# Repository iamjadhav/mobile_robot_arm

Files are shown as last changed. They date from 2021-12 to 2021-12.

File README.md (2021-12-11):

## Mobile Robot Arm

---

## Contributors

1) [Rajan Pande](https://github.com/rpande1996)
Graduate Student of M.Eng Robotics at University of Maryland. 
2) [Aditya Jadhav](https://github.com/iamjadhav)
Graduate Student of M.Eng Robotics at University of Maryland.

## Overview

In today’s rapidly advancing technological world, the ease of access to products and the speed as well as quality with which they are delivered are extremely important. Most of
the companies in the modern world are aware of the advantages these factors bring to their revenue. But to achieve these couple of objectives, they need to act smartly and reduce costs
wherever they can. Reducing production, packaging and shipment costs goes way beyond helping achieve those objectives. And of course, technology plays a significant part of that
advancement. Bringing down labor costs in terms of salary and benefits helps in reducing the aforementioned costs of the companies. Having smart, efficient and low-maintenance
workforce can lead to even greater benefits in saving revenue. Industrial Robots is the proven answer to this question of satisfying customer needs with speed and efficiency to stay or even
get ahead of the competition. Our aim is to build an Mobile Industrial Robot Arm that is designed to help with the loading and unloading of product shipment. While building this Robot Arm,
we intend to make use of smart sensing to have the robot become as automated as possible. The development of the packaging environment is also one of our main subtasks to implement the
entire system. We will be aiming to achieve maximum speed and efficiency in our process of loading and unloading by refining our system elements.

The results are avilable in the Demo section.
The technologies(libraries, tools, systems) used in order to build this project are listed in the next section.

## Technology Used

* Ubuntu 18.04 LTS
* ROS Melodic
* Python Programming Language
* CMake Build System
* SolidWorks Software
* IKpy Library
* Rviz
* Gazebo
* Numpy Library
* Sympy Library

## License 

```
MIT License

Copyright (c) 2021 Rajan Pande, Aditya Jadhav

Permission is hereby granted, free of charge, to any person obtaining a copy
of this software and associated documentation files (the "Software"), to deal
in the Software without restriction, including without limitation the rights
to use, copy, modify, merge, publish, distribute, sublicense, and/or sell
copies of the Software, and to permit persons to whom the Software is
furnished to do so, subject to the following conditions:

The above copyright notice and this permission notice shall be included in all
copies or substantial portions of the Software.

THE SOFTWARE IS PROVIDED "AS IS", WITHOUT WARRANTY OF ANY KIND, EXPRESS OR
IMPLIED, INCLUDING BUT NOT LIMITED TO THE WARRANTIES OF MERCHANTABILITY,
FITNESS FOR A PARTICULAR PURPOSE AND NONINFRINGEMENT. IN NO EVENT SHALL THE
AUTHORS OR COPYRIGHT HOLDERS BE LIABLE FOR ANY CLAIM, DAMAGES OR OTHER
LIABILITY, WHETHER IN AN ACTION OF CONTRACT, TORT OR OTHERWISE, ARISING FROM,
OUT OF OR IN CONNECTION WITH THE SOFTWARE OR THE USE OR OTHER DEALINGS IN THE 
SOFTWARE.
```

## Demos

Gazebo Demo:

- [Final Pick and Place](https://www.youtube.com/watch?v=QyFkN3RfSUs)

Rviz Demo:

- [Rviz](https://www.youtube.com/watch?v=fZ4QtwVQR7c)

## How to Build and run scripts

- Setup: Navigate to the launch folder and open final_world.world file
and replace "/<your-workspace-location>/" with your workspace location. Otherwise the 
world will not load properly.

- Demo - cd into the catkin_ws/src and type in, 

```
git clone --recursive https://github.com/iamjadhav/mobile_robot_arm
cd ..
catkin_make
source devel/setup.bash
roslaunch robot_arm arm_launch.launch
```

- To run tele-op for mobile base or arm links, open another terminal,
cd into the src folder of the package and type,

```
python teleop_template.py/arm_movements.py
```

- FK and IK validation: cd into kinematics_validation folder of the package and run,

```
python forward_kinematics.py/inverse_kinematics.py
```

- Jacobian and T-matrices: cd into kinematics_validation folder of the package and run,

```
python jacobian_calculator.py
``` 

## Set of Assumptions 

- The environment of the robot (world) obeys gravity, and the surface is continuous
  and flat.
- The objects are placed on the edge of the platforms so as to be within the workspace
  of the Robot Arm when it moves closer to them.
- The obstacles are detected by the laser and a soft warning is displayed. It is
  assumed that the operator is on the lookout for such warnings when the robot arm
  is visibly close to any obstacle.
- The platform heights are adjusted according to the workspace of the robot arm.
- The end-effector of the robot arm is designed considering the shape of the object.
  They make grasping of the object drastically convenient.

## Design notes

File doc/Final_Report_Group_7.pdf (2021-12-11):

## ENPM662 Introduction to Robot Modeling Final Project Proposal

## Mobile Industrial Robot Arm

Authors: Rajan Pande (117306002) & Aditya Jadhav (117389616)

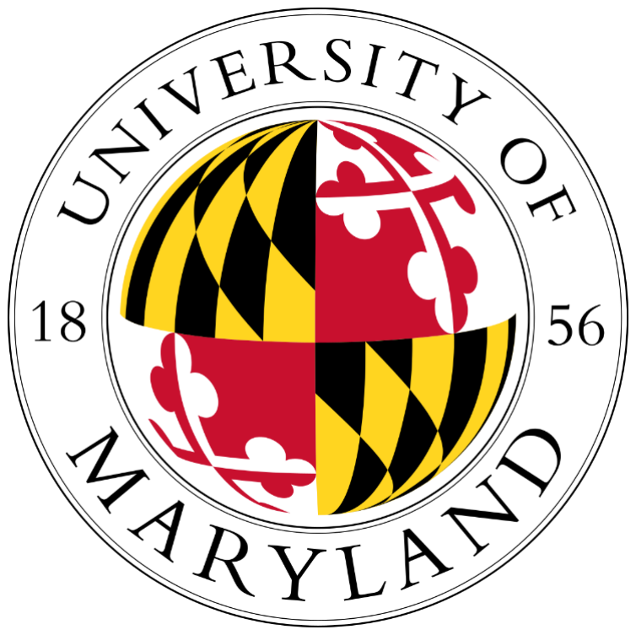
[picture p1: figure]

## Table of Contents

## Introduction

This document provides an in-depth report for our ENPM662 Final Project Mobile Robot Industrial Arm. The document provides an in-depth proposal for ENPM662 Project 2. The document contains different sections each with information about certain aspects of the project. The project was concerned with developing a mobile robot arm of industrial standards from scratch. The ‘Introduction’ section describes the structure of the report. ‘Application’ section describes the applications that this robot can be deployed for a useful function. The sections ‘Robot Type’ and ‘Dimensions’ detail the in-depth information of the type, structure of the robot, its specifications and physical dimensions, material, and actuators used, and the system specifications. The ‘CAD models’ section describes and demonstrates the different stages of the development of the mobile robot arm. The next section ‘DH Parameters’ shows the Denavit-Hartenberg parameters of the mobile robot arm which are calculated using the Spong’s convention. Next four sections are ‘Forward Kinematics & Inverse Kinematics’, ‘Forward Kinematics Validation & Inverse Kinematics Validation’ respectively and are the sections about our study of the Forward and Inverse Kinematics of the mobile robot arm and the validation of FK and IK.
Section ‘Workspace Study’ describes the workspace of the mobile robot arm containing the maximum reach of the arm with its available joint rotations. ‘Assumptions’ section states the assumptions of the project for producing the optimal output out of the developed system. The next section ‘Control Method’ is about the control mechanism used for the mobile robot arm which is the Proportional-Integral-Derivative controller. It also outlines the types of ROS controllers that exist and the ones that are used for the arm. The ‘Gazebo Visualization’ is mainly about the Gazebo setup of the project containing details about the custom world and its components as well as the entire setup with the arm. ‘RViz Visualization’ highlights the laser outputs which are obtained from RViz for the LaserScan topic. Sections ‘Problems’ and ‘Lessons Learned’ represent the problems we faced during several stages of the development process and the solutions/learnings we deployed. ‘Conclusion’ section summarizes the project outcomes and concludes the project. ‘Future Works’ outlines the ambitious goals that can be achieved building on this project. Finally, the ‘References’ section enlists the references we used to acquire knowledge about different aspects of Robot Modeling and our project.

## Application

The primary motivation for us to work on this project was the Stretch (https://spectrum.ieee.org/stretch-is-boston-dynamics-take-on-a-practical-mobile-manipulator-for-warehouses) Robot developed by Boston Dynamics, which is deployed for mobile, automated case handling for more efficient warehouse operations. Stretch is a versatile mobile robot for case handling, designed for easy deployment in existing warehouses. It unloads trucks and builds pallets faster, eliminating the need for new fixed infrastructure. It can be used to automate case handling anywhere in the warehouse with advanced mobility, reducing the need for fixed infrastructure. The Stretch Robot boasts advanced perception which delivers fast and precise case detection. It has a 7 degrees-of-freedom manipulator arm which allows for long reach and large workspace. It also contains embedded sensing and active control which handles variety of package types while operating at high speeds. The lost lucrative feature of the Stretch Robot for us was the mobile base. We draw inspiration from the mobile base which maneuvers in any direction and navigates obstacles and ramps.
As we were working through the different phases of our development process, we had to change the design of the overall robot as well as the robot arm. We faced problems with center of gravity of the system, the limiting torque of each joint (these will be detailed in the ‘Problems’ section). Consequently, we had to adapt our robots design to overcome these problems. We decided that we will look for inspiration in a robot which is a crucial part of human history, The Mars Rover Curiosity. (https://mars.nasa.gov/msl/spacecraft/rover/arm/) Although, possessing abilities far beyond the ones we desired, it was perfect to look up to for us and proceed with our project.
The mobile robot arm applications such as the ones described above are extremely ambitious real-life applications. Our mobile robot arm, however, is not yet capable of such complex applications, but can definitely achieve the core objectives of Pick ‘n’Place operations in a known and controlled environment.

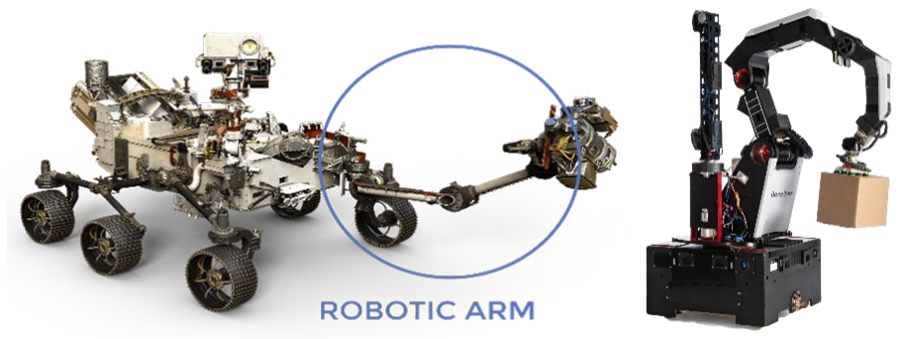
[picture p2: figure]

Figure 1: Curiosity (left) and Stretch (right)

## Robot Type

Under the umbrella of a multitude of currently recognized robot types (https://robots.ieee.org/learn/types-of-robots/) in the world, our mobile robot arm falls under the Industrial Robot Type. An Industrial Robot is a robot system used for manufacturing and its related processes. Industrial Robots are automated, programmable, and capable of movement on three or more axes. Typical applications of robots include welding, painting, assembly, disassembly, pick and place, packaging and labeling, palletizing, product inspection and testing; all accomplished with high endurance, speed, and precision. They can assist in material handling.
The robot arm developed in this project belongs to the Articulated Robots type in Industrial Robots. Articulated Robots are the most common Industrial Robots. They look like a human arm, which is why they are also called robotic arm or manipulator arm. Their articulations with several degrees-of-freedom allow the articulated arms a wide range of movements.

## Dimensions

We have developed a 6 DOF manipulator on a 2 DOF mobile base:

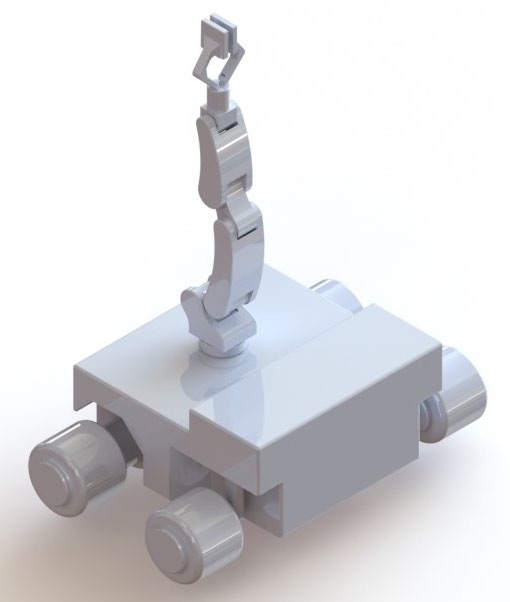
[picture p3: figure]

Property | Dimension
Total Length | 2.00 m
Total Width | 3.22 m
Total Height | 3.91 m
Vertical Reach | 3.98 m
Horizontal Reach | 2.16 m
Wheelbase | 1.25 m
Trackwidth | 2.62 m
Wheel Diameter | 0.62m
Wheel Thickness | 0.50 m
Rotating Arm Length | 0.42 m
Extending Arm Length | 0.90 m
Picking Arm Length | 0.88 m
Jaw Arm Length | 0.30 m
Jaw Length | 0.54 m

## CAD Models

### 1. Robot Arm 1.0:

The initial design had a simple design which would satisfy our basic fallback requirements. However, the drawback of this design was that it had a smaller workspace.

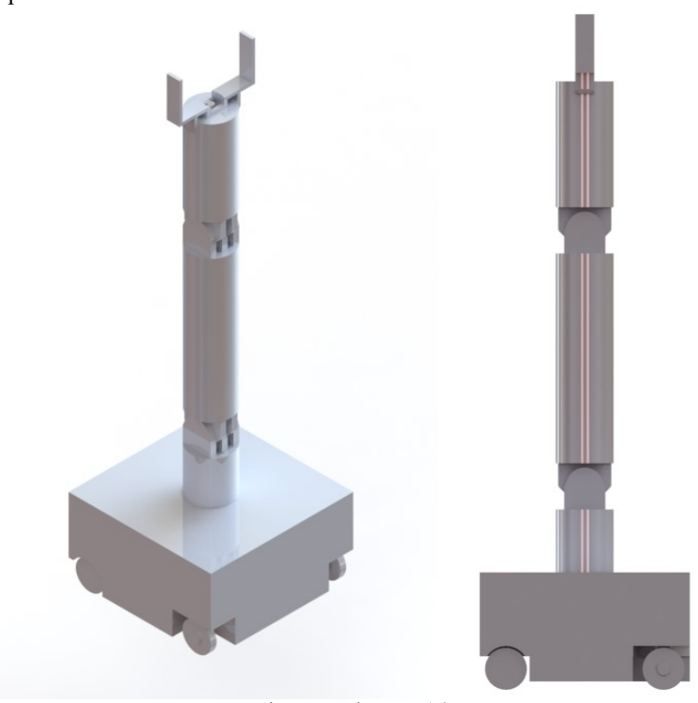
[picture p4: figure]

Figure 3: Robot Arm 1.0

### 2. Robot Arm 2.0:

To increase the workspace, we required to make a few changes to arm design. The major drawback of this design was inability to operate the jaws in ROS.

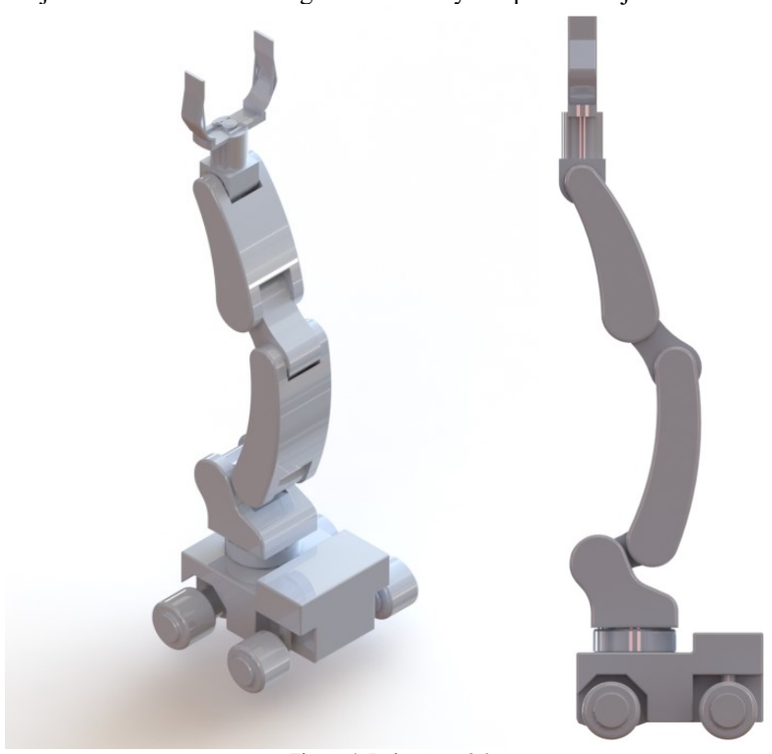
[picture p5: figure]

Figure 4: Robot Arm 2.0

### 3. Robot Arm 3.0:

We thought, maybe the issue with the earlier design was the complicated jaw mechanism. So, we converted it to a simple prismatic joint. However, we weren’t still able to actuate the jaws.

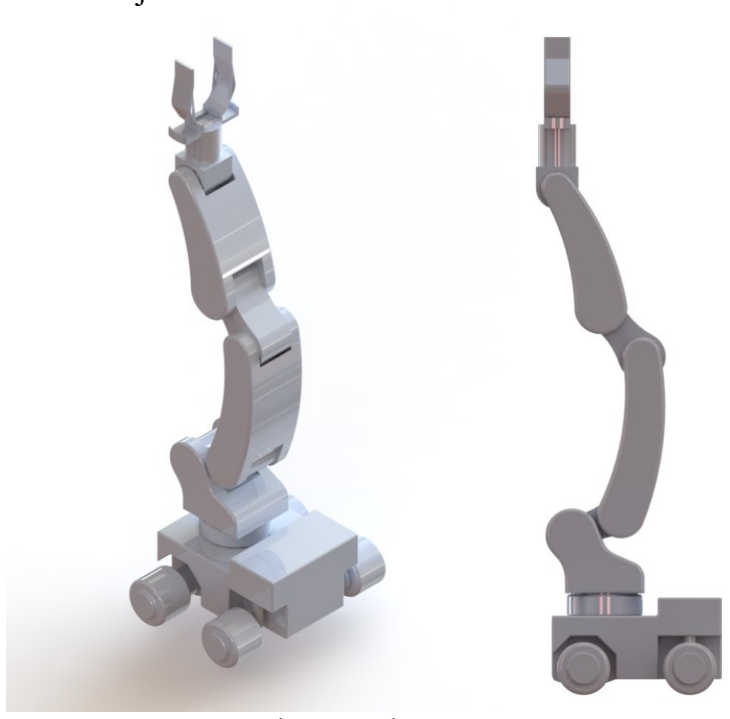
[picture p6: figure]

Figure 5: Robot Arm 3.0

### 4. Robot Arm 4.0:

We finally came up with a solution of designing a simple revolute mechanism for the jaws. Additionally, to increase the stability of the robot, we designed a wider mobile base for the manipulator.

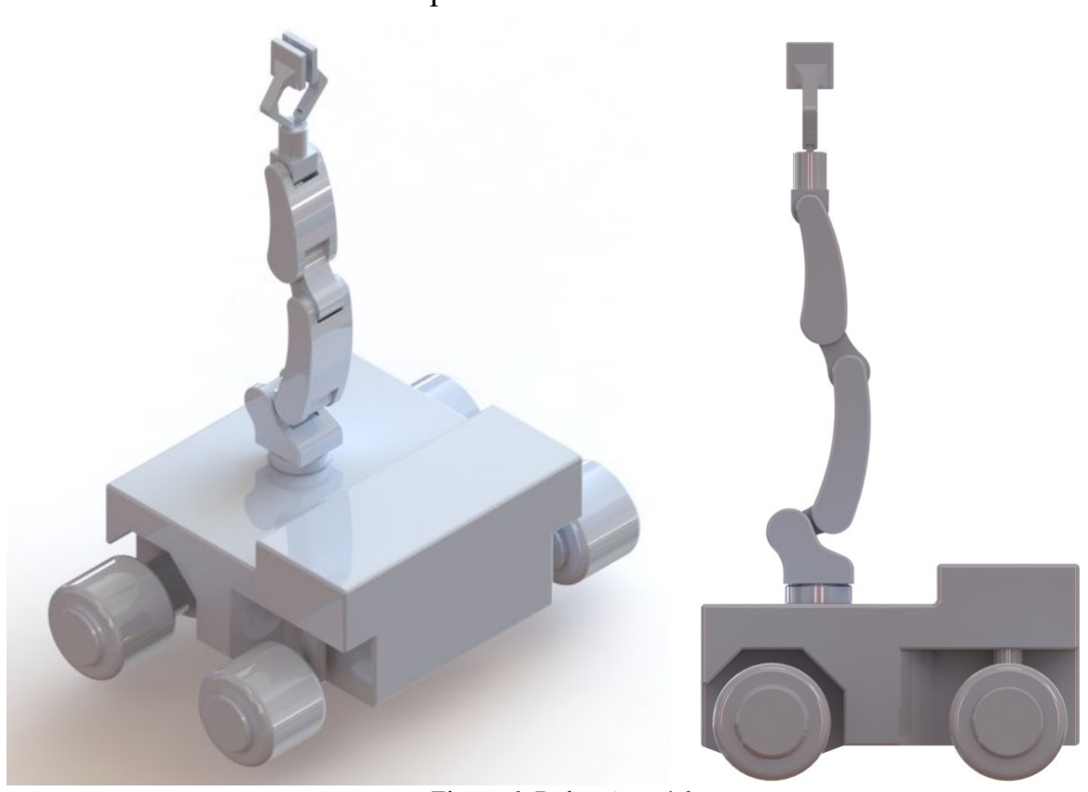
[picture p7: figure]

Figure 6: Robot Arm 4.0

## DH Parameters

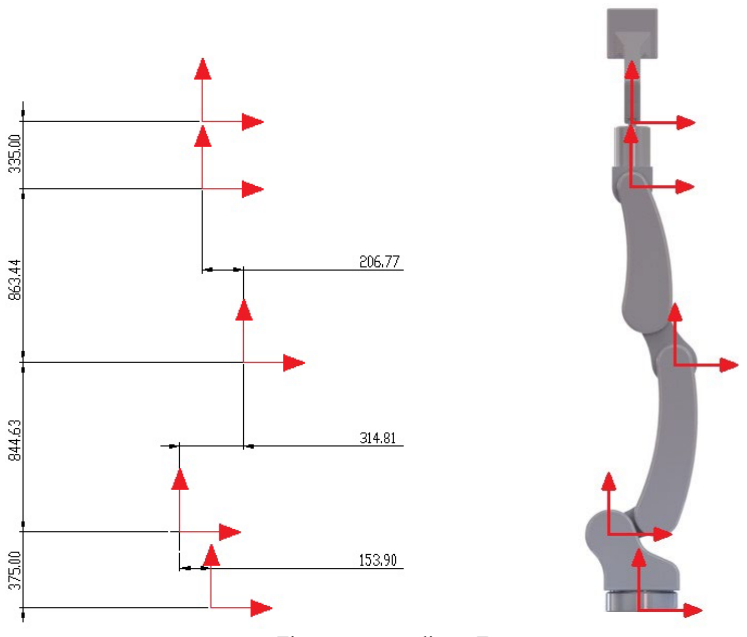
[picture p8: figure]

Figure 7: Co-ordinate Frame

Link | ai | di | αi | di
1 | 153.90 | 375 | π/2 | th1*
2 | 314.81 | 844.63 | 0 | th2*
3 | 206.77 | 863.44 | 0 | th3*
4 | 0 | 335 | 0 | th4*

## Forward Kinematics and Inverse Kinematics

Jacobian and Transformation Matrix Calculator:

1. import numpy as np
2. import sympy as sy
3. from sympy import nsimplify 4.
5. def s(x):
6. return sy.sin(x)
7.
8. def c(x):
9. return sy.cos(x)
10.
11. th, al, a, d, th1, th2, th3, th4, Z1, Z2, Z3, Z4, d1, d2, d3, d4, t = sy.symbols(
12. 'th, al, a, d, th1, th2, th3, th4, Z1, Z2, Z3, Z4, d1, d2, d3, d4, t')
13.
14. A = sy.Matrix([[c(th), -s(th) * c(al), s(th) * s(al), a * c(th)],
15. [s(th), c(th) * c(al), -c(th) * s(al), a * s(th)],
16. [0, s(al), c(al), d],
17. [0, 0, 0, 1]])
18.
19. th_list = [th1, th2, th3, th4]
20. al_list = [pi / 2, 0, 0, 0]
21. d_list = [375, 844.63, 863.44, 335]
22. a_list = [153.9, 314.81, 206.77, 0]
23. init_th = [pi/3, 0, -pi/4, pi]
24.
25. def calculate_A_matrix(ali, ai, thi, di):
26. | global A, e | A_transform = nsimplify(A.subs({al: ali, a: ai, th: thi, d: di}),
27. tolerance=1e-3, rational=True)
28. return A_transform
29.
30. def calculate_T_matrix():
31. A1 = calculate_A_matrix(al_list[0], a_list[0], th_list[0], d_list[0])
32. A2 = calculate_A_matrix(al_list[1], a_list[1], th_list[1], d_list[1])
33. A3 = calculate_A_matrix(al_list[2], a_list[2], th_list[2], d_list[2])
34. A4 = calculate_A_matrix(al_list[3], a_list[3], th_list[3], d_list[3]) 35.
36. T1 = A1
37. T2 = (T1 * A2)
38. T3 = (T2 * A3)
39. T4 = (T3 * A4)
40. return T1, T2, T3, T4
41.
42. T1, T2, T3, T4 = calculate_T_matrix() 43.
44. def ZMatrix_calculator(T1, T2, T3, T4):
45. Z1 = T1[:3, 2]
46. Z2 = T2[:3, 2]
47. Z3 = T3[:3, 2]
48. Z4 = T4[:3, 2]
49. ZMatrix = [Z1, Z2, Z3, Z4]
50. return ZMatrix
51.
52. def Jcalculator(joint_angle):
53. global T4
54. th = [th1, th2, th3, th4]
55. Th_values = [joint_angle[0], joint_angle[1], joint_angle[2], joint_angle[3]] 56.
57. j = T4[:3, 3]
58. ZMatrices = ZMatrix_calculator(T1, T2, T3, T4)
59.

60. j1 = j.jacobian(th)
61.
62. Z = ZMatrices[0].row_join(ZMatrices[1].row_join(ZMatrices[2].row_join(ZMatrices[3]))) 63.
64. j2 = j1.col_join(Z)
65. j2 = nsimplify(change_values(j2, Th_values), tolerance=1e-3, rational=True)
66. j2 = np.array(j2)
67. return j2
68.
69. def change_values(J_updated, theta):
70. J_updated = J_updated.subs({th1: theta[0],
71. th2: theta[1], th3: theta[2], th4: theta[3]})
72. J_updated = nsimplify(J_updated, tolerance=1e-3, rational=True)
73. return J_updated
74.
75. joint_angles =[0, 0, pi/2, 0]
76. T4 = nsimplify(T4.subs({th1:joint_angles[0], th2:joint_angles[1], th3:joint_angles[2],
77. th4:joint_angles[3]}), tolerance=1e-5, rational=True)
78. J = Jcalculator(th_list)
79. print("Final Transformation Matrix", T4)
80. print("Jacobian Matrix", J)

## FK Validation and IK Validation

Libraries required IKPY [5]:

pip install ikpy
Forward Kinematics Validator:
1. import ikpy.chain
2. import numpy as np
3. def deg2rad(th):
4. return th * np.pi / 180
5.
6.
7. my_chain = ikpy.chain.Chain.from_urdf_file("robot_arm.urdf")
8. th1 = float(input("Enter rotation (in deg) for Rotating Arm: "))
9. th2 = float(input("Enter rotation (in deg) for Extending Arm: "))
10. th3 = float(input("Enter rotation (in deg) for Picking Arm: "))
11. th4 = float(input("Enter rotation (in deg) for Jaw Arm: "))
12.
13. target_angle = [0, deg2rad(th1), deg2rad(th2), deg2rad(th3), deg2rad(th4), 0]
14. position = my_chain.forward_kinematics(target_angle)
15.
16. print("Input joint angles: (%s, %s, %s, %s, %s, %s)" % (target_angle[0],
17. target_angle[1],
18. target_angle[2],
19. target_angle[3],
20. target_angle[4],
21. target_angle[5]))
22.
23. print("X coordinate for end effector: ", position[0, 3])
24. print("Y coordinate for end effector: ", position[1, 3])
25. print("Z coordinate for end effector: ", position[2, 3])

Inverse Kinematics Validator:

1. import ikpy.chain
2. import numpy as np
3. def rad2deg(th):
4. return th * 180 / np.pi
5.
6.
7. my_chain = ikpy.chain.Chain.from_urdf_file("robot_arm.urdf")
8. x = float(input("Enter x coordinate: "))
9. y = float(input("Enter y coordinate: "))
10. z = float(input("Enter z coordinate: "))
11. target_position = [x, y, z]
12. angles = my_chain.inverse_kinematics(target_position)
13. print("Input position: (%s, %s, %s)" % (target_position[0],
14. target_position[1],
15. target_position[2]))
16. print("Angle for Rotating Arm: %s deg" % rad2deg(angles[1]))
17. print("Angle for Extending Arm: %s deg" % rad2deg(angles[2]))
18. print("Angle for Picking Arm: %s deg" % rad2deg(angles[3]))
19. print("Angle for Jaw Arm: %s deg" % rad2deg(angles[4]))
20.

## Workspace Study

The kinematic analysis of a manipulator is an important part of the robot study. workspace study is a part of the kinematic analysis of the robot. Working space of robotic arm is the reference point at the end of the robot arm to achieve the set point of space. Working space is discussed from the geometric aspects of the work performance of the robot arm. Analytical work is used to determine the spatial configuration of the robot arm. Working space represents the range of activities, which is a parameter of the ability to work the robot arm kinematics and is also an important indicator. Robot arm and the sizes of workspace according to the design requirements, must reach the required working space, which is reasonable to judge about the structure, operability, and flexibility of the robot arms. Workspace model for robot planning and control information provide important constraints, such as working space was determined according to the mechanical interference between the robot arm and the robot arm motion planning to avoid obstacles.[4] (https://iopscience.iop.org/article/10.1088/1755-1315/170/4/042166)
Horizontal reach of the mobile robot arm is 2.16 m, and the vertical reach is 3.98 m. The workspace is of a parabolic cone shape

## Assumptions

Following assumptions are made for our project:
- The environment of the robot (world) obeys gravity, and the surface is continuous and flat.
- The objects are placed on the edge of the platforms so as to be within the workspace of the Robot Arm when it moves closer to them.
- The obstacles are detected by the laser and a soft warning is displayed. It is assumed that the operator is on the lookout for such warnings when the robot arm is visibly close to any obstacle.
- The platform heights are adjusted according to the workspace of the robot arm.
- The end-effector of the robot arm is designed considering the shape of the object. They make grasping of the object drastically convenient.

## Control Method

The conventional Proportional-Integral-Derivative method is used as the control mechanism of the mobile robot arm. The PID control method is intended for use where you have a straightforward control problem that you just need to throw a PID loop at. It has one purpose and focuses on doing it well. It has numerous features that ease the task of adding a controller and tuning the control loop. Several examples are provided.
Kp, Ki, Kd: Are the values to be used for proportional, integral, and derivative gains. These values are used by the node unless overridden by dynamic reconfiguration. Defaults are 1.0, 0, and 0 for Kp, Ki and Kd.

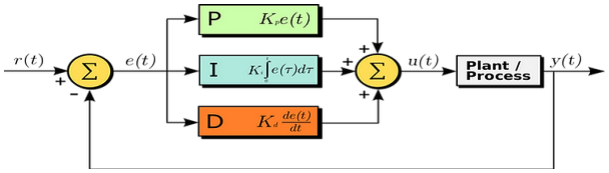
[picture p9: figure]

Figure 8: PID Controller

We have tuned our PID values for all the joints present in our system and included in the ROS controller mechanism.

ROS Control is a set of packages that includes controller interface, controller manager, transmissions, hardware interfaces and control toolbox. All these packages together will allow you interact and control the joint actuators of the robot.

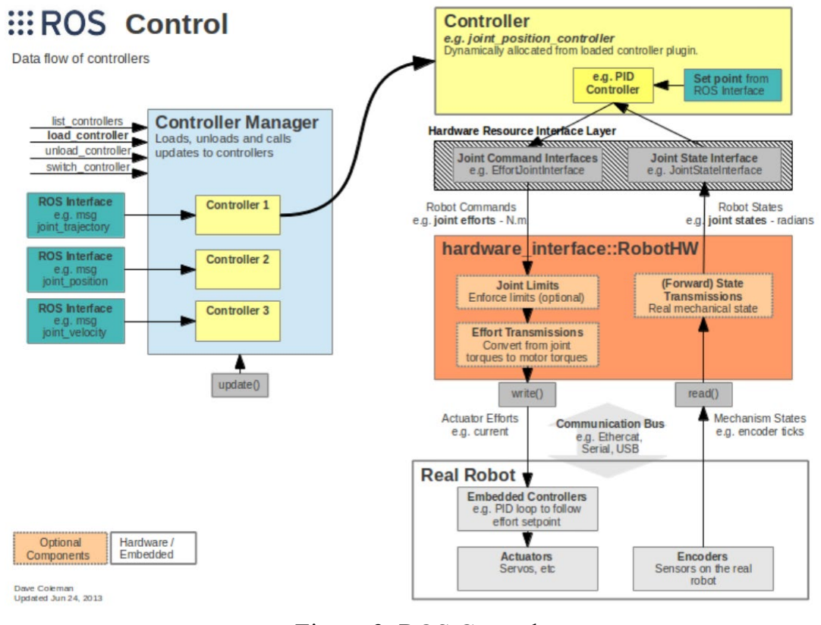
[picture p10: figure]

Figure 9: ROS Control

The basic and most used ROS controllers are:

- joint_state_controller
- effort_controllers
- velocity_controllers
- position_controllers
- joint_trajectory_controllers
We have used joint_state_controller, effort_controllers, and velocity_controllers in this project.
The joint_state_controller reads all joint positions and publishes them on to the topic "/joint_states". This controller does not send any command to the actuators.

The velocity_controller is used for the rear-transmission of the base to provide velocity. The effort_controller used as effort_controllers/JointPositionController, accepts the position [radians (or) meters] value as input. Error (goal position -current position) is mapped to output effort command through a PID loop.

## Gazebo Visualization

- We have designed a custom world from the ground up which includes a C-Shaped wall encapsulating the warehouse-like setup.
- The warehouse like setup consists of two tables which are designed with a height that considers the Robot Arm’s reach.
- The Objects which are placed on table 1 (close to the north-west corner of the wall) are placed and designed according to the assumptions stated in the ‘Assumptions’ section.
- The mobile Robot Arm spawns at the Origin (Blue line: Y-Axis) of the custom world.

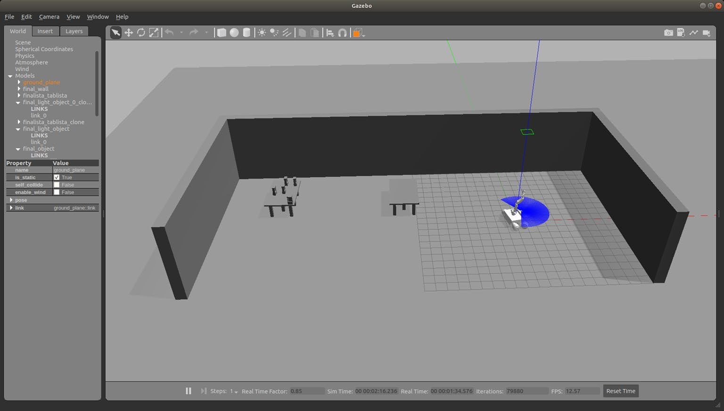
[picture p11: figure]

Figure 10: Gazebo Initial Setup
- Final Gazebo Pick and Place Video: Link (https://www.youtube.com/watch?v=QyFkN3RfSUs)

## RViz Visualization

A ROS and Gazebo compatible Laser is used for Obstacle Detection of the system. The laser uses gazebo_ros_head_hokuyo_controller as the gazebo control plugin. The Tele-Op program uses 0, 30, 90, 120, and 300 degree beams of the laser sensor to detect the obstacles. The Robot Arm can be seen in front of multiple objects and the laser detects all the objects comfortably which is evident from the RViz laser beams shown below.

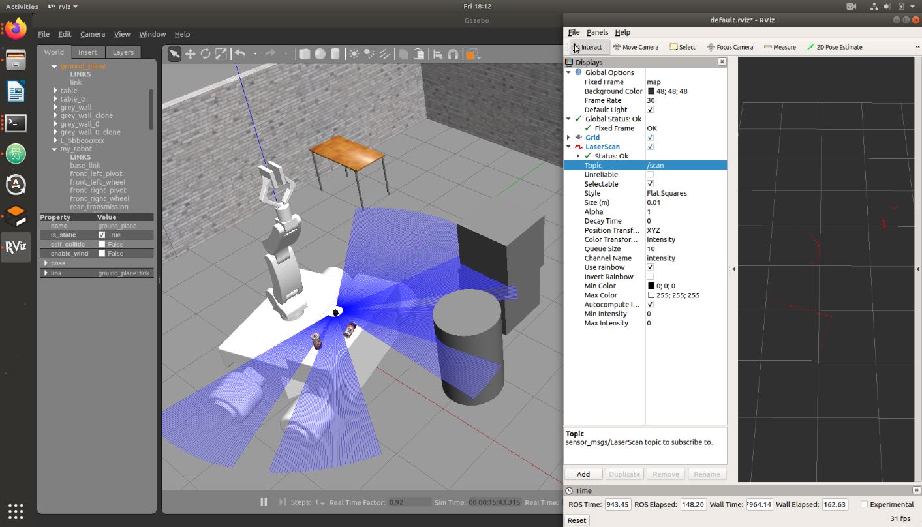
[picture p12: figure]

Figure 11: RViz Visualization
- Final RViz Video: Link (https://youtu.be/fZ4QtwVQR7c)

## Problems

- Center of Gravity Issue:

We encountered a CG issue with the design of the Robot Arm. Initially, the height of the Robot Arm was close to 15 feet, but the wheel-base was not wide enough to support most moments of the links of the Robot Arm. The robot would topple from the slightest of link rotations.
- Controller and Effort Issue:

We faced a controller issue for the arm joints which caused the arm links to collapse into themselves. The limit efforts for each link were not set properly in the initial stages, this combined with the wrong controllers made the arm links get tangled into each other and defy gravity.
- Effort Limits Issue:

Apart from setting the effort values limit, we needed to set the upper and lower limit values with positive or negative signs, which specified the directions of the link limits.
- Oscillating Object:

We have designed a custom world with custom objects inside it. One of the initial objects we designed was defying gravity and swinging like a pendulum when placed on a surface. We got around this by opening Gazebo with admin permissions and then designing.

## Lessons Learned

- SolidWorks:
- Learned to design Prismatic joints for end-effectors.
- Learned design of manipulator for a wider workspace.
- Learned URDF export method in SolidWorks.
- ROS:
- Learned structure and working of a ROS package
- Learned Publisher – Subscriber architecture
- Learned how nodes communicate with each other over different topics.
- Learned the use of .launch, .xacro, and integration files in a ROS package.
- Learned about ROS Control Architecture: Controller types to use, when and where to use them.
- Gazebo:
- Learned how to design a custom world using custom made objects.
- Learned how to use Model Editor to design custom objects.
- Learned how to insert, move, rotate, and scale objects inside a world.
- Other:
- Learned about Forward and Inverse Kinematics of a robot manipulator.
- Learned about various tags of the URDF and XACRO files.
- Learned how to interface and work with sensors of a robot.
- Learned about PID tuning of components of a robot.

## Conclusions

In this Project, we started from learning the basic Robot Modeling concepts and worked our way up to some complex concepts used in the field of Robotics. We were able to achieve all of our primary goals designing and implementing a 6 DOF (8 DOF system), lightweight, durable, and end-effector flexible mobile robot arm with at least once sensor for object detection/avoidance and perform pick and place task. In the process of completing this project, we learned many concepts, architectures, and structures in ROS, SolidWorks, Gazebo, FK, and IK.
GitHub: Link (https://github.com/iamjadhav/mobile_robot_arm)

## Future Works

We set out developing this project with a set of primary as well as ambitious goals. We were able to achieve the primary set of goals and one of our ambitious goals. We had a goal of designing at least a 4 DOF manipulator which is durable and lightweight. We were able to design a 6 DOF manipulator (8 DOF system) with additional links to increase workspace.
The future work for this project includes making the mobile robot arm completely autonomous given a set of goals. We would like to add extra sensors to help with the autonomy of the robot. To go hand in hand with the autonomous behavior of the robot, we would be aiming to implement a planning algorithm which enables the robot arm to automatically avoid colliding with obstacles.

## References

[1] SolidWorks Official Tutorials. (http://www.solidworkstutorials.com/)
[2] ROS Textbook: A Gentle Introduction to ROS by Jason M. O’Kane.
[3] Stretch Article on Spectrum IEEE. (https://spectrum.ieee.org/stretch-is-boston-dynamics-take-on-a-practical-mobile-manipulator-for-warehouses)
[4] Kinematics Analysis and Workspace Calculation of a 3-DOF Manipulator, Jianqiang Zhu and Fang Tian 2018 IOP Conf. Ser.: Earth Environ. Sci. 170042166.
[5] IKPY Library (https://github.com/Phylliade/ikpy)

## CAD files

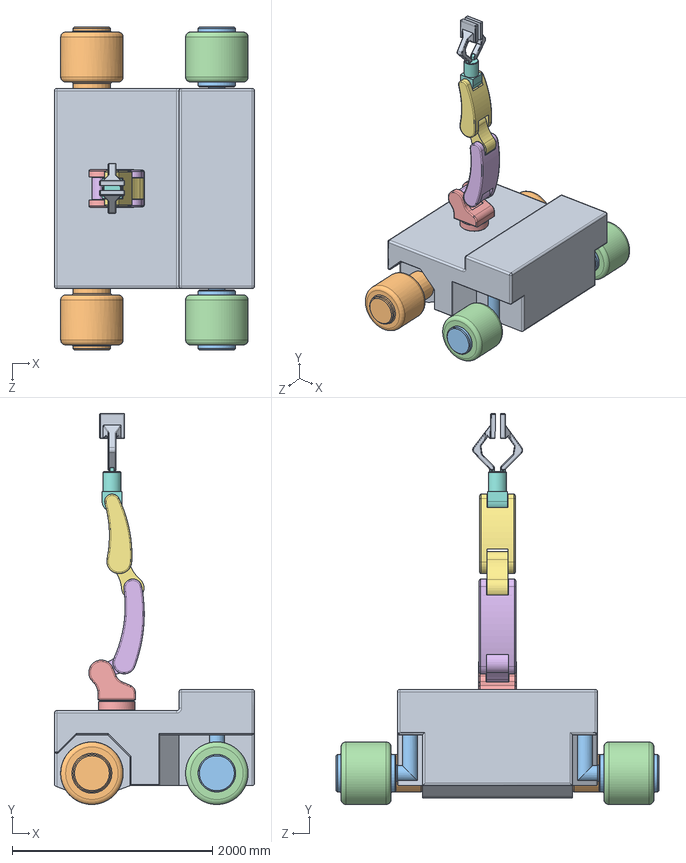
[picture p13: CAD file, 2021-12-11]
solidworks_assembly/robot_arm.SLDASM
2000.0 x 3904.9 x 3225.0 mm
trolley
rear_axle
pivot x 2
wheel x 2
rot_arm
ext_arm
pick_arm
jaw_arm
jaw_updated x 2

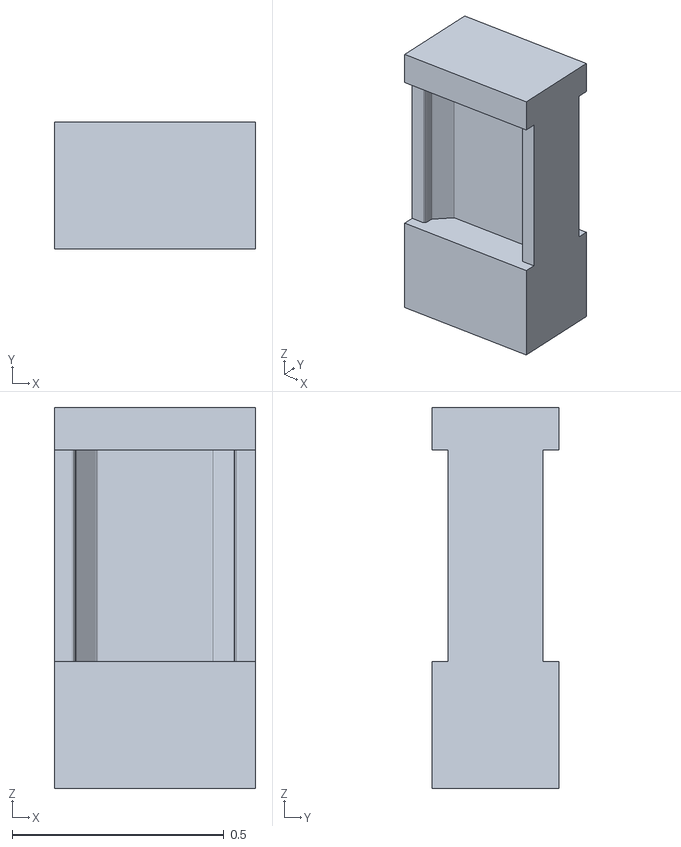
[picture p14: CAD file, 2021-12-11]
custom_models/object.stl
0.475 x 0.3 x 0.9

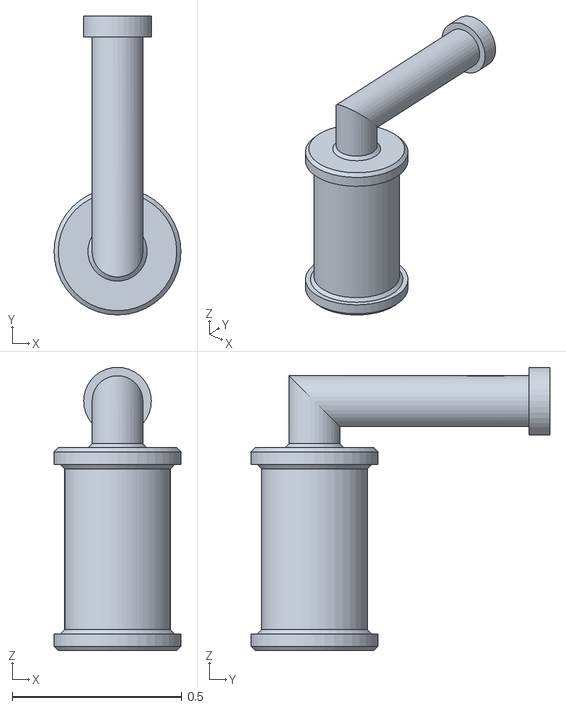
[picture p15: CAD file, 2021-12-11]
meshes/front_right_pivot.STL
0.375 x 0.883 x 0.838

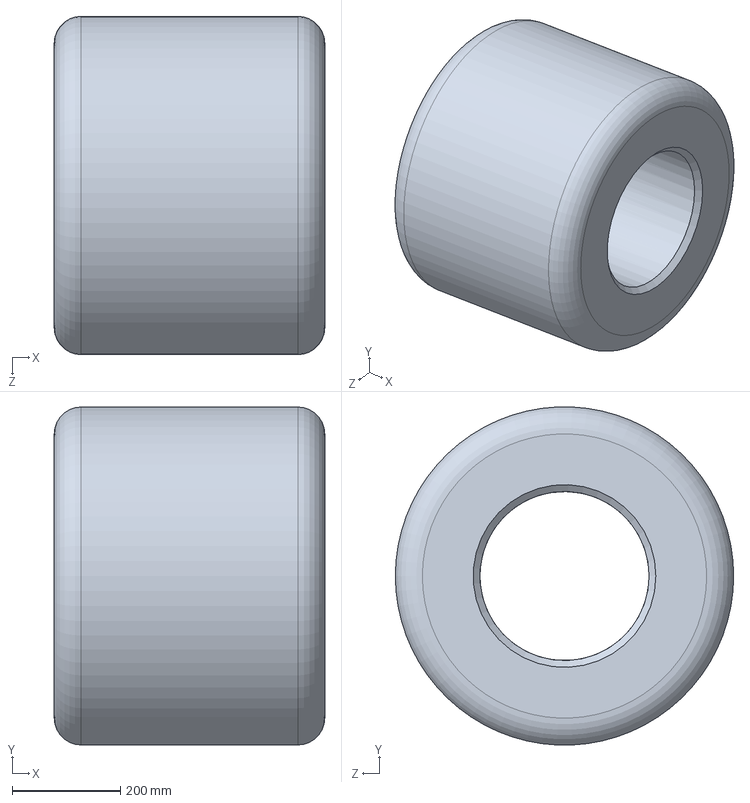
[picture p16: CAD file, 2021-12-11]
solidworks_assembly/wheel.SLDPRT
500.0 x 624.4 x 625.0 mm

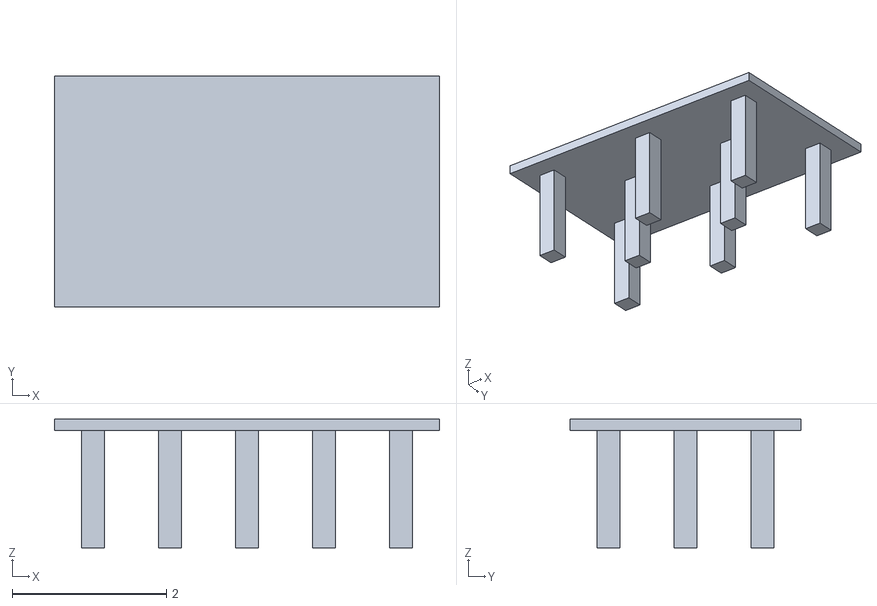
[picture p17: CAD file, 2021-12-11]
custom_models/table.stl
5.00 x 3.00 x 1.67

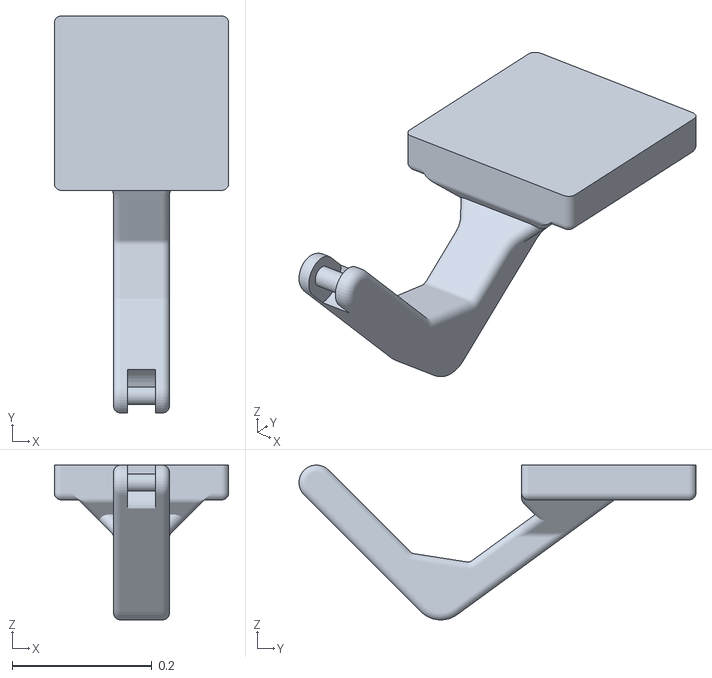
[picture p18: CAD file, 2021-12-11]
meshes/right_jaw.STL
0.25 x 0.569 x 0.222

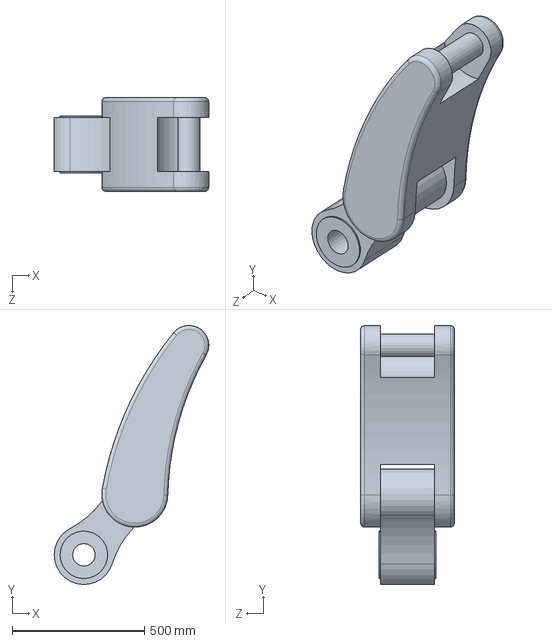
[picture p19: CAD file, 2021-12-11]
solidworks_assembly/pick_arm.SLDPRT
585.5 x 980.7 x 355.0 mm

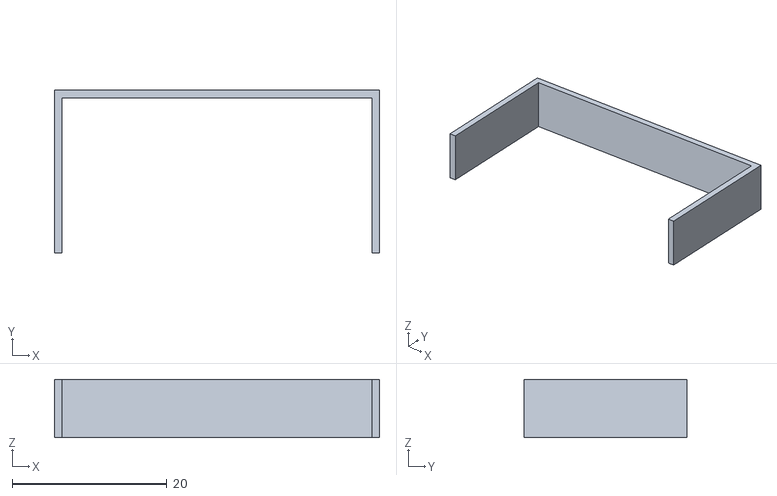
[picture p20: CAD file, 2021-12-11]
custom_models/wall.stl
42.0 x 21.0 x 7.50

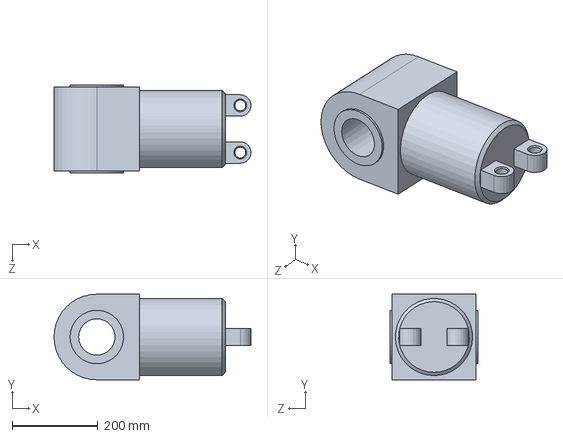
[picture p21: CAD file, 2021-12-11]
solidworks_assembly/jaw_arm.SLDPRT
460.0 x 200.0 x 205.0 mm

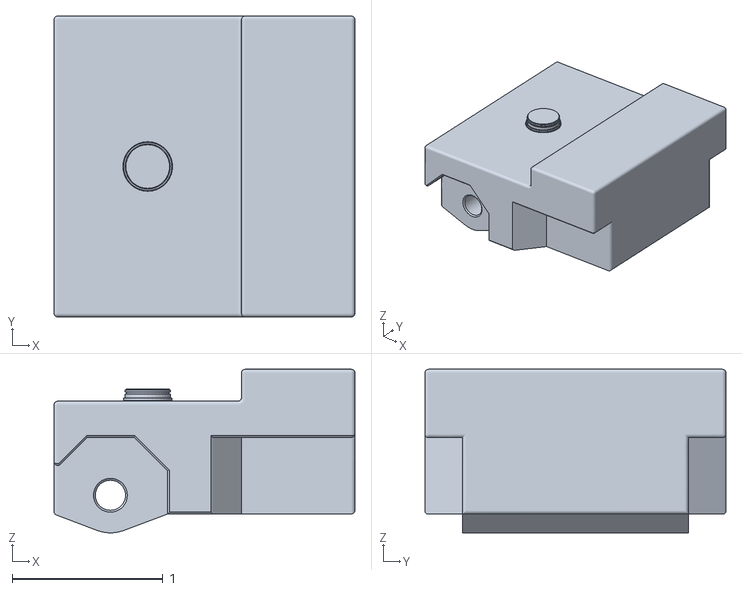
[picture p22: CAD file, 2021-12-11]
meshes/base_link.STL
2.00 x 2.00 x 1.09

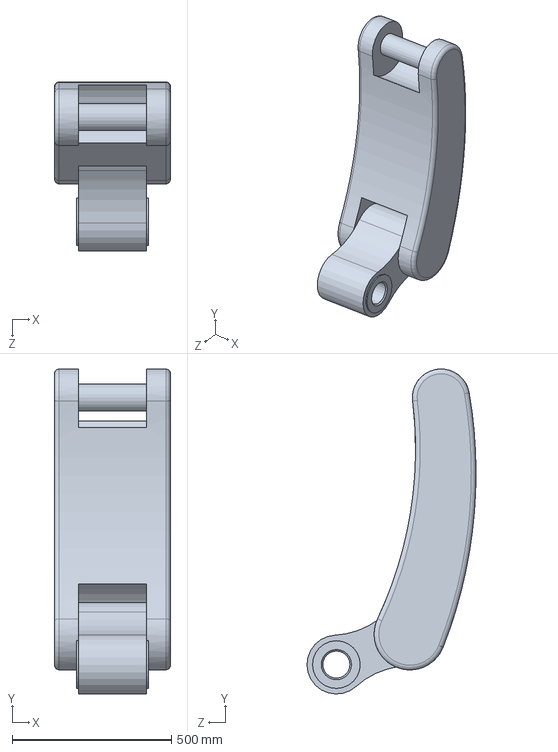
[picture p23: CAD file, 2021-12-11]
solidworks_assembly/ext_arm.SLDPRT
365.0 x 1021.6 x 531.5 mm

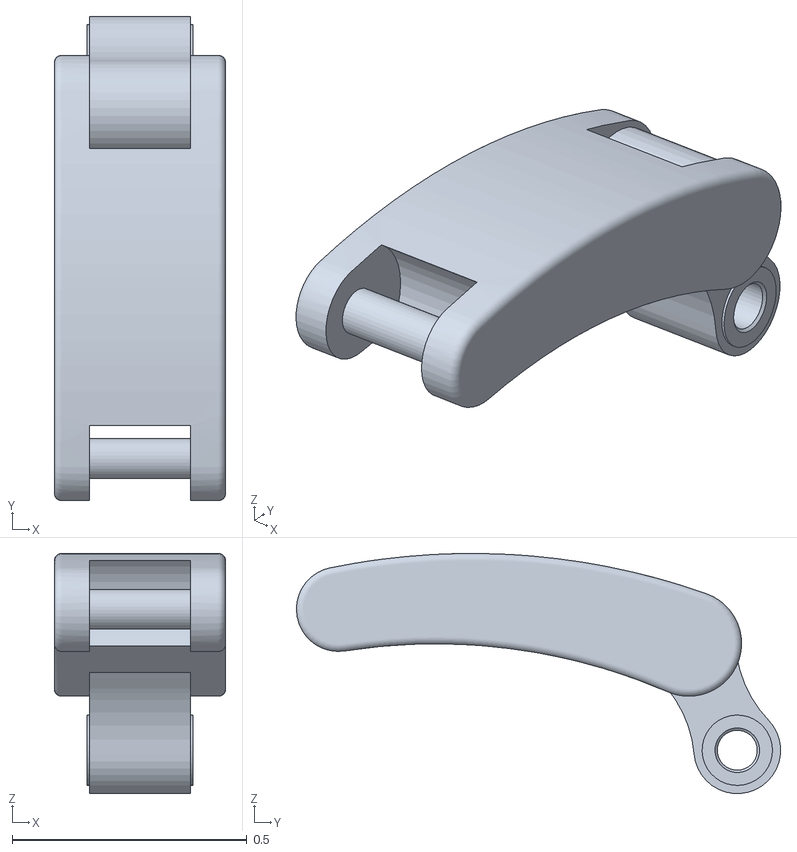
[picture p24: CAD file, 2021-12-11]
meshes/extending_arm.STL
0.365 x 1.03 x 0.512

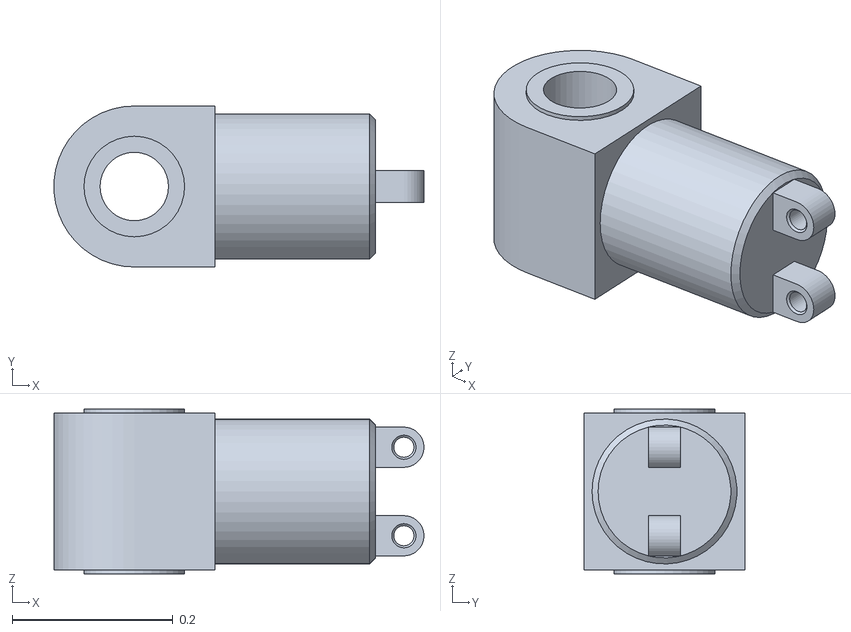
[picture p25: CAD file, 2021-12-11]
meshes/jaw_arm.STL
0.46 x 0.2 x 0.205

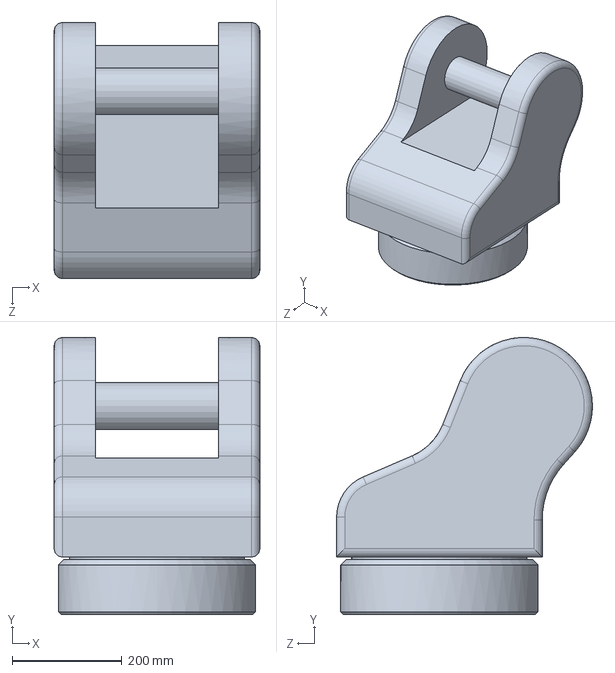
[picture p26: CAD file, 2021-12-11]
solidworks_assembly/rot_arm.SLDPRT
375.0 x 504.9 x 466.4 mm

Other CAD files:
meshes/front_left_pivot.STL
meshes/picking_arm.STL
solidworks_assembly/trolley.SLDPRT
meshes/front_right_wheel.STL
meshes/front_left_wheel.STL
meshes/left_jaw.STL
meshes/rear_transmission.STL
meshes/rotating_arm.STL
solidworks_assembly/jaw_updated.SLDPRT
solidworks_assembly/pivot.SLDPRT
solidworks_assembly/rear_axle.SLDPRT

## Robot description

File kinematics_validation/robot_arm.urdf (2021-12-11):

<?xml version="1.0" encoding="utf-8"?>
<!-- This URDF was automatically created by SolidWorks to URDF Exporter! Originally created by Stephen Brawner (brawner@gmail.com) 
     Commit Version: 1.6.0-1-g15f4949  Build Version: 1.6.7594.29634
     For more information, please see http://wiki.ros.org/sw_urdf_exporter -->
<robot name="robot_arm">
  <link name="base_link">
    <inertial>
      <origin xyz="0.0507897286232543 0.436442409160195 -3.92896700520566E-09" rpy="0 0 0" />
      <mass value="473.229494217205" />
      <inertia ixx="160.514734864114" ixy="-15.4185513941369" ixz="-3.82101723548316E-06" iyy="285.818254553099" iyz="-2.08542755229281E-06" izz="189.479114171076" />
    </inertial>
    <visual>
      <origin xyz="0 0 0" rpy="0 0 0" />
      <geometry>
        <mesh filename="package://robot_arm/meshes/base_link.STL" />
      </geometry>
      <material name="">
        <color rgba="0.792156862745098 0.819607843137255 0.933333333333333 1" />
      </material>
    </visual>
    <collision>
      <origin xyz="0 0 0" rpy="0 0 0" />
      <geometry>
        <mesh filename="package://robot_arm/meshes/base_link.STL" />
      </geometry>
    </collision>
  </link>
  <link name="rotating_arm">
    <inertial>
      <origin xyz="-8.00669290452874E-09 0.220582757890716 -0.0423974889335031" rpy="0 0 0" />
      <mass value="6.0730182118069" />
      <inertia ixx="0.150417694007526" ixy="-4.40604724929895E-09" ixz="3.00388694943259E-08" iyy="0.160364457024367" iyz="0.0353800394951801" izz="0.154043342259197" />
    </inertial>
    <visual>
      <origin xyz="0 0 0" rpy="0 0 0" />
      <geometry>
        <mesh filename="package://robot_arm/meshes/rotating_arm.STL" />
      </geometry>
      <material name="">
        <color rgba="0.792156862745098 0.819607843137255 0.933333333333333 1" />
      </material>
    </visual>
    <collision>
      <origin xyz="0 0 0" rpy="0 0 0" />
      <geometry>
        <mesh filename="package://robot_arm/meshes/rotating_arm.STL" />
      </geometry>
    </collision>
  </link>
  <joint name="rotating_arm_joint" type="revolute">
    <origin xyz="-0.37722 0 0.75" rpy="1.5708 0 1.5708" />
    <parent link="base_link" />
    <child link="rotating_arm" />
    <axis xyz="0 1 0" />
    <limit lower="-3.14" upper="3.14" effort="30" velocity="0.8" />
  </joint>
  <link name="extending_arm">
    <inertial>
      <origin xyz="-4.27793936461089E-16 -0.381891137777311 0.262623332241788" rpy="0 0 0" />
      <mass value="10.2462174046825" />
      <inertia ixx="0.825359728044462" ixy="-4.74693645664573E-16" ixz="8.41298629675562E-16" iyy="0.228952971983405" iyz="0.170803228096654" izz="0.830893220318168" />
    </inertial>
    <visual>
      <origin xyz="0 0 0" rpy="0 0 0" />
      <geometry>
        <mesh filename="package://robot_arm/meshes/extending_arm.STL" />
      </geometry>
      <material name="">
        <color rgba="0.792156862745098 0.819607843137255 0.933333333333333 1" />
      </material>
    </visual>
    <collision>
      <origin xyz="0 0 0" rpy="0 0 0" />
      <geometry>
        <mesh filename="package://robot_arm/meshes/extending_arm.STL" />
      </geometry>
    </collision>
  </link>
  <joint name="extending_arm_joint" type="revolute">
    <origin xyz="0 0.38 -0.1539" rpy="-0.016689 0 3.1416" />
    <parent link="rotating_arm" />
    <child link="extending_arm" />
    <axis xyz="1 0 0" />
    <limit lower="-1.57" upper="1.57" effort="30" velocity="0.8" />
  </joint>
  <link name="picking_arm">
    <inertial>
      <origin xyz="0.210685599639969 0.379226047227641 -4.91870553987825E-16" rpy="0 0 0" />
      <mass value="8.74716157874975" />
      <inertia ixx="0.615782700335979" ixy="-0.212752584628406" ixz="-1.31978014826064E-16" iyy="0.219378960733766" iyz="1.10030205238793E-15" izz="0.651168793348446" />
    </inertial>
    <visual>
      <origin xyz="0 0 0" rpy="0 0 0" />
      <geometry>
        <mesh filename="package://robot_arm/meshes/picking_arm.STL" />
      </geometry>
      <material name="">
        <color rgba="0.792156862745098 0.819607843137255 0.933333333333333 1" />
      </material>
    </visual>
    <collision>
      <origin xyz="0 0 0" rpy="0 0 0" />
      <geometry>
        <mesh filename="package://robot_arm/meshes/picking_arm.STL" />
      </geometry>
    </collision>
  </link>
  <joint name="picking_arm_joint" type="revolute">
    <origin xyz="0 -0.84976 0.30067" rpy="1.5708 1.3576 -1.5708" />
    <parent link="extending_arm" />
    <child link="picking_arm" />
    <axis xyz="0 0 1" />
    <limit lower="-1.57" upper="1.57" effort="30" velocity="0.8" />
  </joint>
  <link name="jaw_arm">
    <inertial>
      <origin xyz="0.101691353365546 -6.10622663543836E-16 -2.11130689265894E-15" rpy="0 0 0" />
      <mass value="1.78782932155198" />
      <inertia ixx="0.00968992120586809" ixy="-6.61984057590914E-17" ixz="1.40732437569899E-18" iyy="0.0276613343723937" iyz="3.49379032614783E-20" izz="0.0277379744815533" />
    </inertial>
    <visual>
      <origin xyz="0 0 0" rpy="0 0 0" />
      <geometry>
        <mesh filename="package://robot_arm/meshes/jaw_arm.STL" />
      </geometry>
      <material name="">
        <color rgba="0.792156862745098 0.819607843137255 0.933333333333333 1" />
      </material>
    </visual>
    <collision>
      <origin xyz="0 0 0" rpy="0 0 0" />
      <geometry>
        <mesh filename="package://robot_arm/meshes/jaw_arm.STL" />
      </geometry>
    </collision>
  </link>
  <joint name="jaw_arm_joint" type="revolute">
    <origin xyz="0.39805 0.79363 0" rpy="3.1416 0 1.3409" />
    <parent link="picking_arm" />
    <child link="jaw_arm" />
    <axis xyz="0 0 1" />
    <limit lower="-1.57" upper="1.57" effort="30" velocity="0.8" />
  </joint>
  <link name="jaw">
    <inertial>
      <origin xyz="-2.20127401862058E-08 0.327307984309611 -0.0384943409389779" rpy="0 0 0" />
      <mass value="5.47707679901732" />
      <inertia ixx="0.125903884920864" ixy="-3.46190928916787E-09" ixz="-1.77160379032553E-09" iyy="0.0351648457955596" iyz="-0.0266960896948912" izz="0.126769811317934" />
    </inertial>
    <visual>
      <origin xyz="0 0 0" rpy="0 0 0" />
      <geometry>
        <mesh filename="package://robot_arm/meshes/jaw.STL" />
      </geometry>
      <material name="">
        <color rgba="0.792156862745098 0.819607843137255 0.933333333333333 1" />
      </material>
    </visual>
    <collision>
      <origin xyz="0 0 0" rpy="0 0 0" />
      <geometry>
        <mesh filename="package://robot_arm/meshes/jaw.STL" />
      </geometry>
    </collision>
  </link>
  <joint name="jaw_joint" type="revolute">
    <origin xyz="0.335 0 0.055" rpy="-3.1211 0 1.5708" />
    <parent link="jaw_arm" />
    <child link="jaw" />
    <axis xyz="1 0 0" />
    <limit lower="-1.57" upper="1.57" effort="30" velocity="0.8" />
  </joint>
</robot>

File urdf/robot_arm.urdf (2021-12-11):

<?xml version="1.0" encoding="utf-8"?>
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
<robot name="robot_arm">
  <link name="base_link">
    <inertial>
      <origin xyz="0.05079 0.43644 -3.929E-09" rpy="0 0 0" />
      <mass value="473.23" />
      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
    </inertial>
    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
  </link>
  <link name="rear_transmission">
    <inertial>
      <origin xyz="-3.9489E-15 -2.7756E-17 0" rpy="0 0 0" />
      <mass value="68.804" />
      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
    </inertial>
    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
  </link>
  <joint name="rear_transmission_joint" type="continuous">
    <origin xyz="-0.625 0 0.125" rpy="-1.5708 0 -1.5708" />
    <parent link="base_link" />
    <child link="rear_transmission" />
    <axis xyz="1 0 0" />
  </joint>
  <link name="front_left_pivot">
    <inertial>
      <origin xyz="-5.2398E-07 0.19906 -0.33437" rpy="0 0 0" />
      <mass value="10.4" />
      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
    </inertial>
    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
  </link>
  <joint name="front_left_pivot_joint" type="continuous">
    <origin xyz="0.62278 0.875 0" rpy="1.5708 0 0" />
    <parent link="base_link" />
    <child link="front_left_pivot" />
    <axis xyz="0 1 0" />
  </joint>
  <link name="front_left_wheel">
    <inertial>
      <origin xyz="0.25 0 -4.6629E-15" rpy="0 0 0" />
      <mass value="18.056" />
      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
    </inertial>
    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
  </link>
  <joint name="front_left_wheel_joint" type="continuous">
    <origin xyz="0 0.125 -0.1875" rpy="0 1.5708 0" />
    <parent link="front_left_pivot" />
    <child link="front_left_wheel" />
    <axis xyz="1 0 0" />
  </joint>
  <link name="front_right_pivot">
    <inertial>
      <origin xyz="-5.2398E-07 0.19906 -0.33437" rpy="0 0 0" />
      <mass value="10.4" />
      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
    </inertial>
    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
  </link>
  <joint name="front_right_pivot_joint" type="continuous">
    <origin xyz="0.62278 -0.875 0" rpy="1.5708 0 3.1416" />
    <parent link="base_link" />
    <child link="front_right_pivot" />
    <axis xyz="0 1 0" />
  </joint>
  <link name="front_right_wheel">
    <inertial>
      <origin xyz="-0.25 2.9143E-16 4.5519E-15" rpy="0 0 0" />
      <mass value="18.056" />
      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
    </inertial>
    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
  </link>
  <joint name="front_right_wheel_joint" type="continuous">
    <origin xyz="0 0.125 -0.1875" rpy="3.1416 -1.5708 0" />
    <parent link="front_right_pivot" />
    <child link="front_right_wheel" />
    <axis xyz="1 0 0" />
  </joint>
  <link name="rotating_arm">
    <inertial>
      <origin xyz="-8.0067E-09 0.22058 -0.042397" rpy="0 0 0" />
      <mass value="6.073" />
      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
    </inertial>
    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
  </link>
  <joint name="rotating_arm_joint" type="revolute">
    <origin xyz="-0.37722 0 0.75" rpy="1.5708 0 1.5708" />
    <parent link="base_link" />
    <child link="rotating_arm" />
    <axis xyz="0 1 0" />
    <limit lower="-0.1" upper="0.1" effort="30" velocity="0.8" />
  </joint>
  <link name="extending_arm">
    <inertial>
      <origin xyz="-4.3203E-16 -0.38189 0.26262" rpy="0 0 0" />
      <mass value="10.246" />
      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
    </inertial>
    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
  </link>
  <joint name="extending_arm_joint" type="revolute">
    <origin xyz="0 0.38 -0.1539" rpy="-0.016689 0 3.1416" />
    <parent link="rotating_arm" />
    <child link="extending_arm" />
    <axis xyz="1 0 0" />
    <limit lower="-0.1" upper="0.1" effort="30" velocity="0.8" />
  </joint>
  <link name="picking_arm">
    <inertial>
      <origin xyz="0.21069 0.37923 -4.7848E-16" rpy="0 0 0" />
      <mass value="8.7472" />
      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
    </inertial>
    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
  </link>
  <joint name="picking_arm_joint" type="revolute">
    <origin xyz="0 -0.84976 0.30067" rpy="1.5708 1.3576 -1.5708" />
    <parent link="extending_arm" />
    <child link="picking_arm" />
    <axis xyz="0 0 1" />
    <limit lower="-0.1" upper="0.1" effort="30" velocity="0.8" />
  </joint>
  <link name="jaw_arm">
    <inertial>
      <origin xyz="0.10169 -6.1062E-16 -2.1115E-15" rpy="0 0 0" />
      <mass value="1.7878" />
      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
    </inertial>
    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
  </link>
  <joint name="jaw_arm_joint" type="revolute">
    <origin xyz="0.39805 0.79363 0" rpy="3.1416 0 1.3409" />
    <parent link="picking_arm" />
    <child link="jaw_arm" />
    <axis xyz="0 0 1" />
    <limit lower="-0.1" upper="0.1" effort="30" velocity="0.8" />
  </joint>
  <link name="left_jaw">
    <inertial>
      <origin xyz="-2.2815E-08 0.32731 -0.038494" rpy="0 0 0" />
      <mass value="5.4771" />
      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
    </inertial>
    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
  </link>
  <joint name="left_jaw_joint" type="revolute">
    <origin xyz="0.335 0 -0.055" rpy="0 0 -1.5708" />
    <parent link="jaw_arm" />
    <child link="left_jaw" />
    <axis xyz="1 0 0" />
    <limit lower="-0.1" upper="0.1" effort="30" velocity="0.8" />
  </joint>
  <link name="right_jaw">
    <inertial>
      <origin xyz="-2.2013E-08 0.32731 -0.038494" rpy="0 0 0" />
      <mass value="5.4771" />
      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
    </inertial>
    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
  </link>
  <joint name="right_jaw_joint" type="revolute">
    <origin xyz="0.335 0 0.055" rpy="-3.1211 0 1.5708" />
    <parent link="jaw_arm" />
    <child link="right_jaw" />
    <axis xyz="1 0 0" />
    <limit lower="-0.1" upper="0.1" effort="30" velocity="0.8" />
  </joint>
</robot>

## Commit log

2021-12-11 Adding Solidworks Folders
    [base_link.STL, config_controllers.yaml, extending_arm.STL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]
2021-12-11 Completing the package with launch file custom files src files and FK IK validation files
    [object.stl, robot_arm.urdf, table.stl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]
2021-12-11 Added custom models fk ik validation and solidworks assembly
    [ext_arm.SLDPRT, jaw_arm.SLDPRT, jaw_updated.SLDPRT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]
2021-12-11 Updated readme and launch file
    [object.stl, table.stl, wall.stl]
